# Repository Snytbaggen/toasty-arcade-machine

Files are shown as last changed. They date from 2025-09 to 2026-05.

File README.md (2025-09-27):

# Prerequisites
* Raspberry Pi 4 or greater, tested with 4 GB ram.
* SPI ports enabled on the Raspberry Pi (done in Raspi config)

# Pinouts
Physical pin in parentheses. Names taken from https://pinout.xyz

## Buttons
GPIO 3 (5): Right button \
GPIO 4 (7): Center button \
GPIO 5 (29): Left button \
PWM 0  (32): Center button LED

All buttons are connected to ground, with each pin set up with `PinMode.InputPullUp`. The center button LED uses 12 V,
so the output from the GPIO PWM pin is fed through an opto coupler which controls an NFET transistor.

## RC522 (NFC)
3v3 Power (17): 3v3 \
SPI0 MOSI (19): MOSI \
SPI0 MISO (21): MISO \
GPIO 25   (22): RST \
SPI0 SCLK (23): SCK \
SPI0 CE0  (24): SDA \
Ground    (25): GND

The IRQ pin on the RC522 unit is unconnected.

## WS2812b LED strip
SPI1 MOSI (38): Data

The data line is connected through a logic level shifter. The power line of the LED strip is connected directly
to a 12V power line.

# BoM
* 1x Raspberry Pi 4 (or newer) with at least 4 GB of RAM
* 2x Sanwa 30mm arcade button
* 1x 100 mm arcade button with built-in LED
* 1x 480x800 screen with built-in touch 
* 2 strips of WS2812b compatible LEDs, each with 16 LEDS
* 1x MINI RFIC-RC522 controller
* 1x miniature USB hub
* 1x audio amplifier with speaker

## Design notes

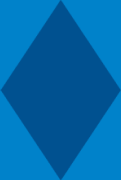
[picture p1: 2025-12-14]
godot/graphics/liss_pattern.png

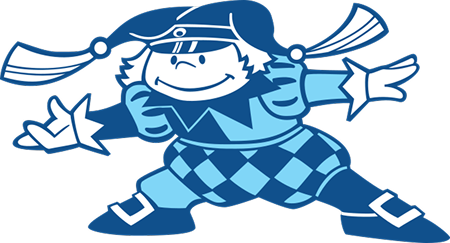
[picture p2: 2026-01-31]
godot/graphics/hype_lisse.png

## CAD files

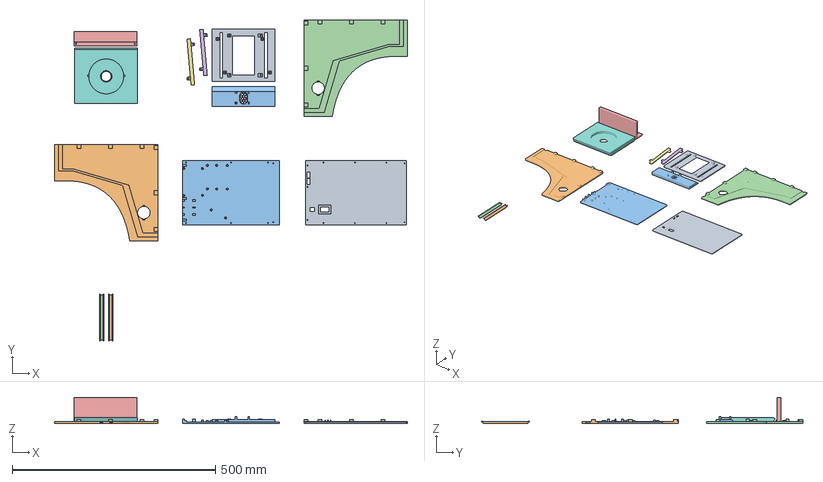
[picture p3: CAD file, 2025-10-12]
design/printables/arcade-cabinet.3mf
869.0 x 790.7 x 65.0 mm
Screen
Speaker
Top
Button
Assembly 1_3
Assembly x 2

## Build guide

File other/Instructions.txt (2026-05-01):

# Necessary libs for running on arm64

## libgodot-wasm.arm64.so
This is a recompilation of the [https://github.com/ashtonmeuser/godot-wasm](godot-wasm) 4.1 plugin to work on arm64 architectures. Version 4.1 must be installed manually or through Godot's AssetLib manager, and then extended with this file.

1. Make sure the 4.1 godot-wasm plugin is installed
2. Navigate to the "addons/godot-wasm" folder in the project
3. Copy `libgodot-wasm.arm64.so` to "bin/Linux"
4. Open `godot-wasm.gdextension` with a text editor and add the following lines:
```
linux.debug.arm64 = "bin/linux/libgodot-wasm.arm64.so"
linux.release.arm64 = "bin/linux/libgodot-wasm.arm64.so"
```

## libgpiod-v1.6.4-arm64.tar.gz
This is an arm64 recompliation of an earlier libgpiod library that's compatible with the current (4.2.0) version of the .NET GPIO lib. This will hopefully make GPIO working if it isn't.

1. Unpack `libgpiod-v1.6.4-arm64.tar.gz` on the Raspberry Pi
2. Copy files in `usr` to their respective directories
3. Copy `etc/local.conf.d/local.conf` or if that file already exists, make sure it contains `/usr/local/lib`)
4. Run `sudo ldconfig`

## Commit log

2025-09-08 Initial commit, working PoC for GPIO input
    [export_presets.cfg]
2025-09-11 Set up viewport to match Raspberry Pi
    This sets up a 480x800 viewport in `main.tscn`, which is then rotated in `root.tscn` to match the orientation of the arcade machine. This works because the window automatically adjusts the viewport t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
2025-09-14 Add physics/jump mechanics, change viewport again, run RPi code in background
    The Lisse node is now using `_physics_process` instead of `_process`, and now has
    features such as gravity, friction and can now double jump. A floor has been added
    so that Lisse doesn't fall to their death.
    The previous approach with drawing portrait graphics didn't work when working with
    `_physics_process`, as those seem to be applied after the rotation has been done.
    Instead everything is now rendered to a rotated `TextureRect` using the output of a
    `GameViewPort` which contains the entire project. Additionally the window now has a
    manual override to match the rotated output.
    The Raspberry Pi code has been mov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
2025-09-17 Add first prototype of a game
2025-09-27 Add rudimentary LED controller
2025-10-12 Move files to Godot folder
    [export_presets.cfg]
2025-10-12 Add first round of design files
    [arcade-cabinet.3mf]
2025-10-12 Read screen edges to LEDs
    This commit adds support for reading and sending the edges of
    the screen to the LED strip. This works by extending the view-
    port width by two pixels, and then sampling the new columns at
    certain intervals.
    The idea is to be able to animate the LEDs by animating things
    on these extra columns, which should be a lot easier than hard-
    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
2025-10-12 Update button pins, add center LED update
    This matches the pins to the PCB and adds code for updating the center LED.
2025-10-20 Update PCB project file
    There was an error where the pulldown resistor was connected to the drain instead of the gate, which is fixed now (although unfortunately not before ordering the PCBs...)
2025-10-22 Fix LED color parsing
2025-10-25 Change orientation of LED reading so it matches the physical layout
2025-10-25 Update PCB design
    The logic shifter doesn't work properly if both +5V and +3.3V is connected, so 5V is removed.
2025-12-14 Update LED logic, add exit button
2025-12-14 Add missing exit button files
2025-12-14 Generalize pin setup and reading
    This also streamlines the reading itself, so we only send out an event whenever a pin state changes
2025-12-14 Begin to add regular UI
    * Add custom theme
    * Add moving background
    * Add placeholder main screen
    [export_presets.cfg]
2025-12-20 Avoid spamming LED update fails if LED controller is not initialized
2025-12-27 Add game selector, rework navigation
    Also adds on-screen keyboard and a lot of other stuff (I've worked in this for a few days over christmas and can't be bothered to split everything up)
    [export_presets.cfg]
2026-01-30 Add better toast and NFC logic
    [export_presets.cfg]
2026-01-30 Make exit button do different thing in dev and prod
2026-01-30 Replace SQLite database with Json
    There are severe performance issues when writing to disk on a Raspberry Pi, sometimes freezing the program for several seconds until the write is done. This commit disables the database and uses JSON files instead, which are written to disk every 15 minutes and on exit, mitigating the problem a bit.
    Once I figure out why the performance is so slow the database will be reenabled.
2026-01-31 Add score saving for Flappy Bird
    [export_presets.cfg]
2026-05-01 Add first version of Doom, migrate to arm64
    This version adds a webassembly version of Doom. It also adds a recompilation of the godot-wasm library that runs on arm64, as it had no arm support out of the box. It's a work in progress, but it's running and is somewhat playable.
    The project has been running on arm32 until now, but as godot-wasm requires features only available in arm64 a switch needed to be done. Moving to a 64-bit distro caused issues with the GPIO libraries, as the 64-bit versions are not compatible with the project's libraries. An older, compatible version has been compiled and is provided if a reinstall is needed in the future.
    [export_presets.cfg]
